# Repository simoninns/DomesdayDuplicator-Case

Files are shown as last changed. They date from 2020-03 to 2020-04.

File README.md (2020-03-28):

# Introduction
This repository contains a 3D printable case design for the Domesday Duplicator.

The case is designed using OpenSCAD and full source code is included.  There are also ready-made STL files for the various parts and materials if you don't want to build them yourself in OpenSCAD.

The case design contains multiple materials however you can easily remix the design using OpenSCAD customization GUI if you wish to print in a single material only (simply deselect the 'fill out text' and 'add logo' options and re-render).  Ready-made single material STL files are also included.

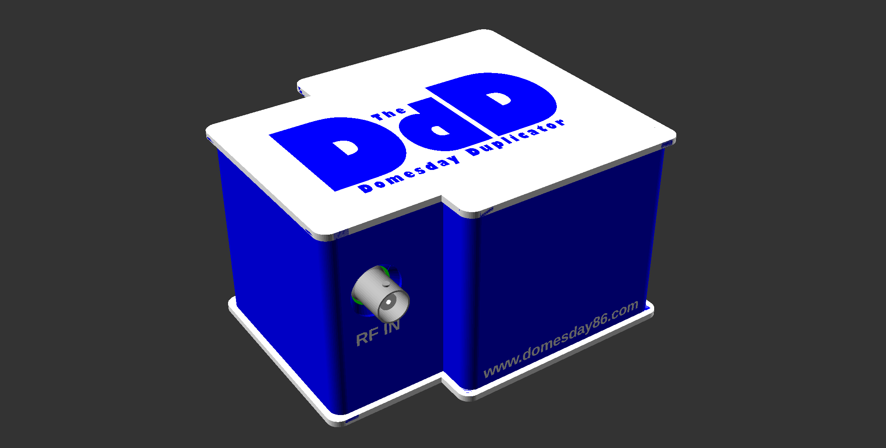
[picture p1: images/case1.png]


# Printing instructions

## Overview

The model has been printed and tested on the Prusa MK3S/MMU2S printer. All parts fit on a 20x20 printing bed.

The OpenSCAD source files provide a parameter interface that allows you to render either the whole model or the individual parts (ready for STL (or other 3D format) export).  This requires OpenSCAD 2019.05 or later.

## Recommended print settings
* Material: PLA Blue and PLA White
* Layer: 0.20mm (Quality)
* Infill: 15%
* Supports: None
* Notes: The upper and lower case parts simply snap together.  4x M3 6mm screws are required to hold the electronics in place.

## Print time
Clearly this depends on your printer and it's settings.  For the 2 colour multi-material print the time was 11h 15m for both the upper and lower case.  For single-material printing to time was 8h 30m.

## Notes
The design also includes approximate renderings of the FPGA board, the DdD board and the USB3 board.  These are to assist with the design process and are not intended for printing.

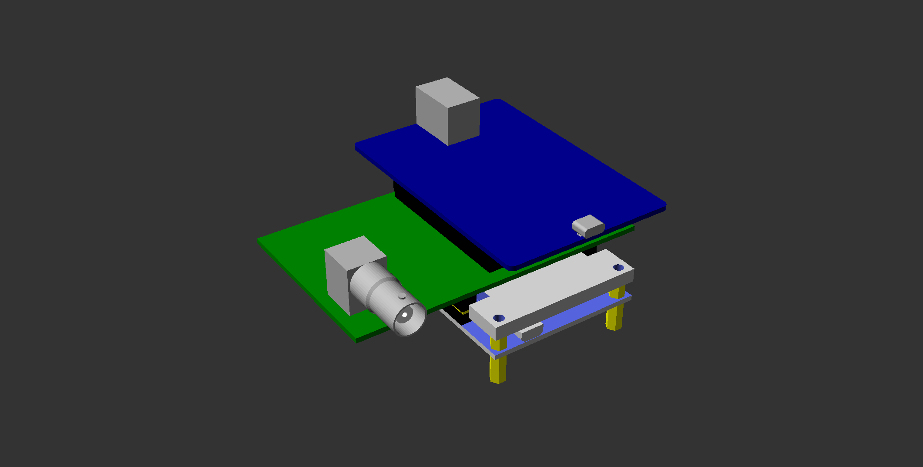
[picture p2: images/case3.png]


# Author

The DomesdayDuplicator case is designed and maintained by Simon Inns.

# Licensing

## OpenSCAD source files - software license (GPLv3)

    This is free software: you can redistribute it and/or modify
    it under the terms of the GNU General Public License as published by
    the Free Software Foundation, either version 3 of the License, or
    (at your option) any later version.
    
    This program is distributed in the hope that it will be useful,
    but WITHOUT ANY WARRANTY; without even the implied warranty of
    MERCHANTABILITY or FITNESS FOR A PARTICULAR PURPOSE.  See the
    GNU General Public License for more details.
    
    You should have received a copy of the GNU General Public License
    along with this program.  If not, see <http://www.gnu.org/licenses/>.

## 3D model file - Creative Commons license (Creative Commons BY-SA 4.0)

Please see the following link for details: https://creativecommons.org/licenses/by-sa/4.0/

You are free to:

Share - copy and redistribute the material in any medium or format
Adapt - remix, transform, and build upon the material
for any purpose, even commercially.

This license is acceptable for Free Cultural Works.

The licensor cannot revoke these freedoms as long as you follow the license terms.

Under the following terms:

Attribution - You must give appropriate credit, provide a link to the license, and indicate if changes were made. You may do so in any reasonable manner, but not in any way that suggests the licensor endorses you or your use.

ShareAlike - If you remix, transform, or build upon the material, you must distribute your contributions under the same license as the original.

No additional restrictions - You may not apply legal terms or technological measures that legally restrict others from doing anything the license permits.

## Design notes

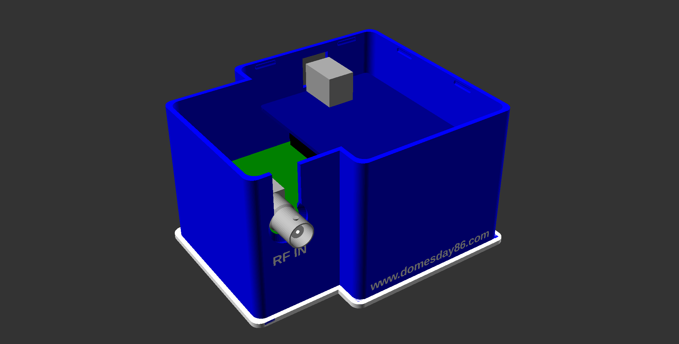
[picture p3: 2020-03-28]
images/case2.png

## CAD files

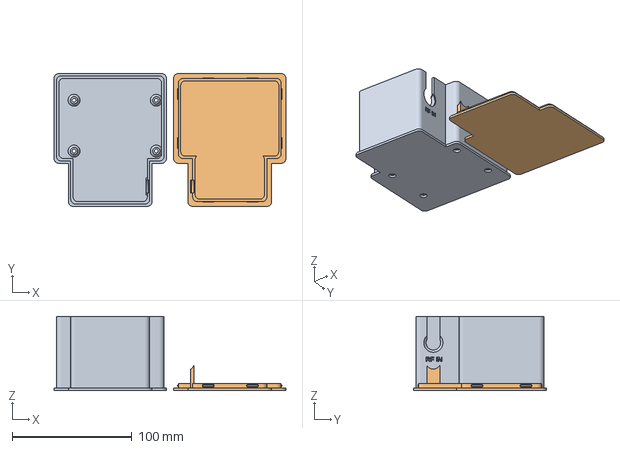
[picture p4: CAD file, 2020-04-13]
3mf/multi_material.3mf
193.9 x 111.0 x 62.0 mm
base_material1.stl
top_material1.stl

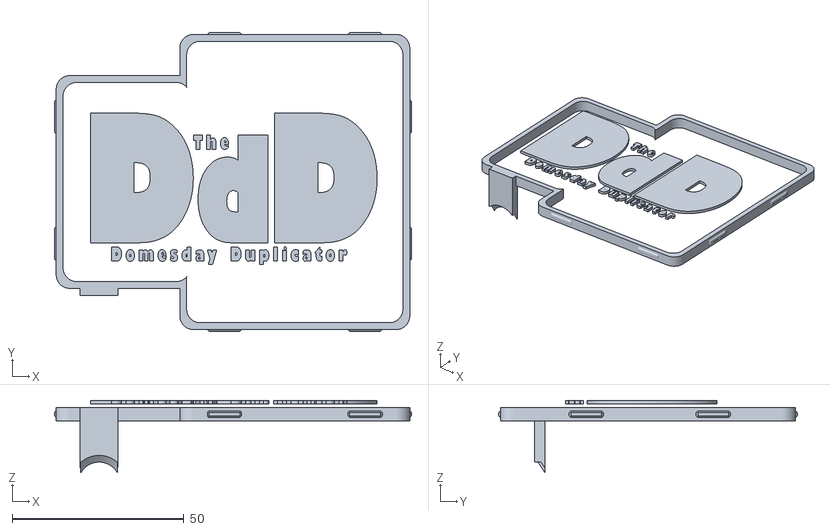
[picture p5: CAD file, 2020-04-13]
stl/top_material2.stl
104.0 x 87.0 x 21.0

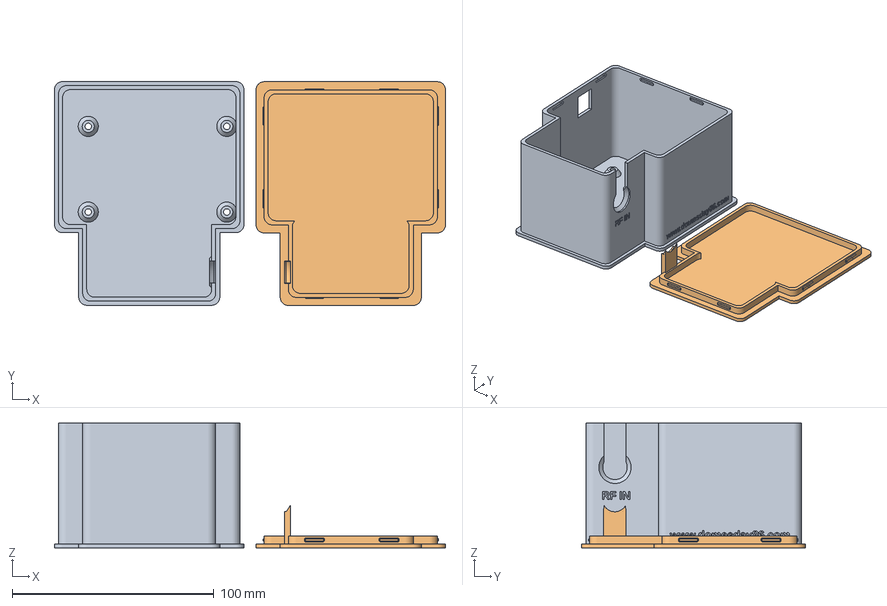
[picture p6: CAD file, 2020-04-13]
3mf/single_material.3mf
194.0 x 111.1 x 62.0 mm
single_material_base.stl
single_material_top.stl

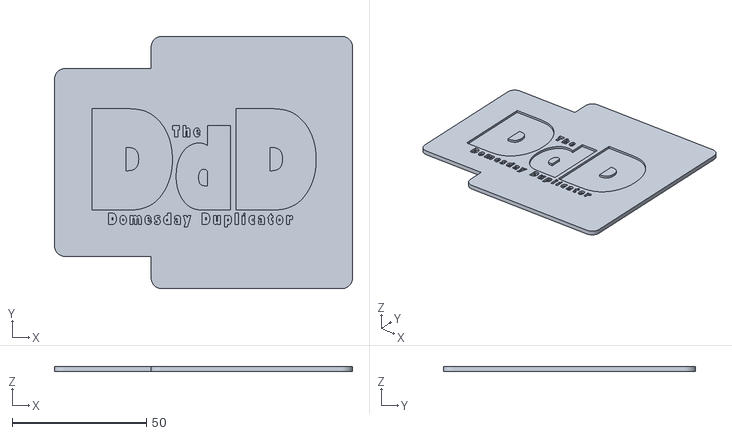
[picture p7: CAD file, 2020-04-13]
stl/top_material1.stl
111.0 x 94.0 x 2.00

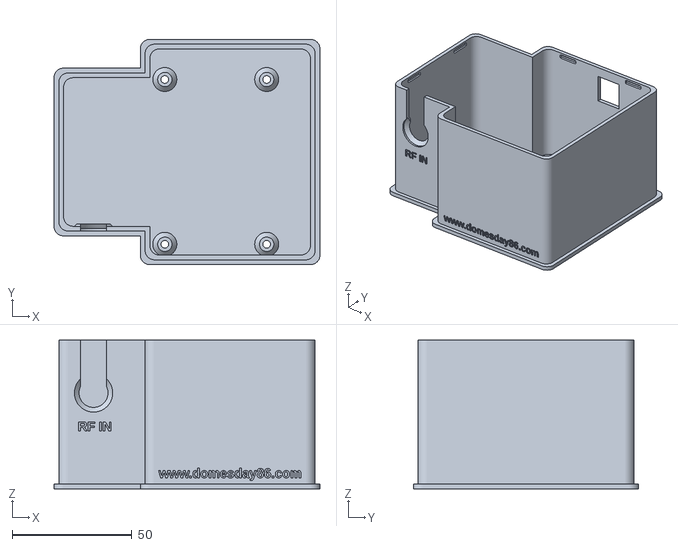
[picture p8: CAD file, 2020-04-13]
stl/single_material_base.stl
111.0 x 94.0 x 62.0

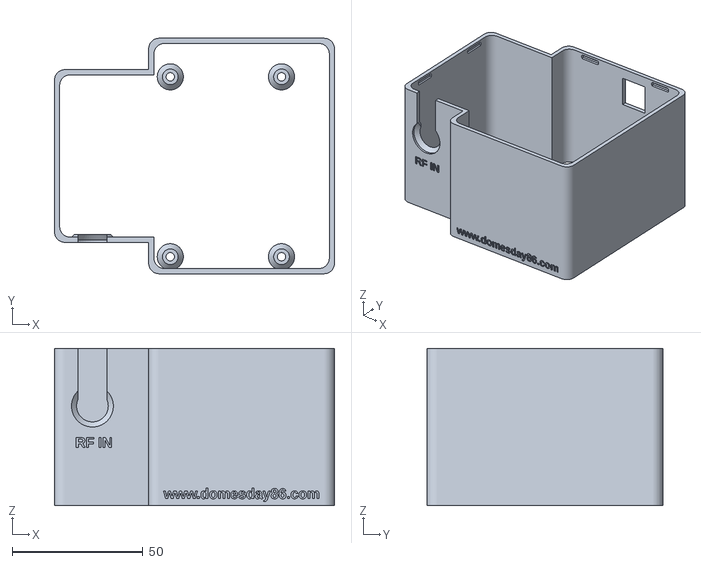
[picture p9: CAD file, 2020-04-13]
stl/base_material2.stl
107.0 x 90.0 x 60.0

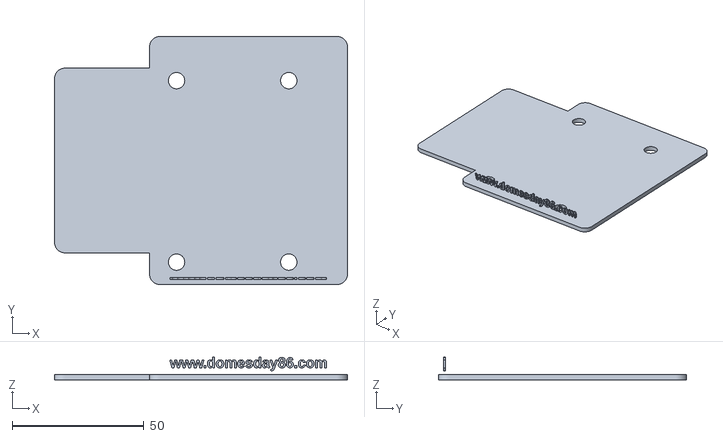
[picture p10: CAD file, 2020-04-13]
stl/base_material1.stl
111.0 x 94.0 x 8.63

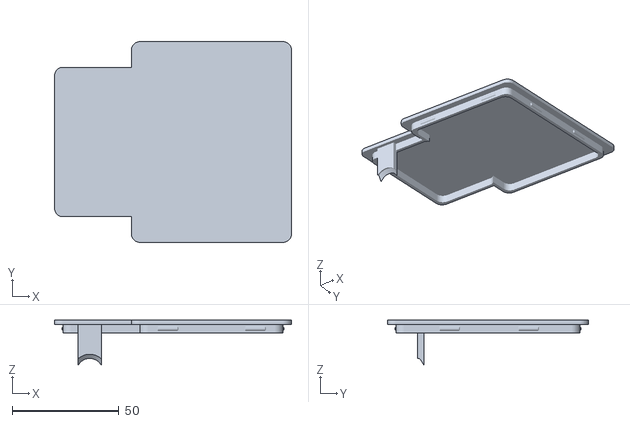
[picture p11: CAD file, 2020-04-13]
stl/single_material_top.stl
111.0 x 94.0 x 21.0

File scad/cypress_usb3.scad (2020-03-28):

/************************************************************************

	cypress_usb3.scad
    
	Domesday Duplicator - 3D Printed Case
    Copyright (C) 2020 Simon Inns
	
    This file is part of Domesday Duplicator.
    
    This is free software: you can redistribute it and/or modify
	it under the terms of the GNU General Public License as published by
	the Free Software Foundation, either version 3 of the License, or
	(at your option) any later version.
    
    This program is distributed in the hope that it will be useful,
    but WITHOUT ANY WARRANTY; without even the implied warranty of
    MERCHANTABILITY or FITNESS FOR A PARTICULAR PURPOSE.  See the
    GNU General Public License for more details.
    
    You should have received a copy of the GNU General Public License
    along with this program.  If not, see <http://www.gnu.org/licenses/>.
	
    Email: simon.inns@gmail.com
    
************************************************************************/

include <BOSL/constants.scad>
use <BOSL/shapes.scad>
use <BOSL/transforms.scad>

// Draw the female header (7mm pins)
module usb3_female_header()
{
    color("black") cuboid([5,51,8], center = false);
}

// Draw the PCB
module usb3_pcb()
{
    color("darkblue") cuboid([56, 82.3, 1.6], center = false, fillet = 2, edges = EDGE_BK_RT+EDGE_BK_LF+EDGE_FR_RT+EDGE_FR_LF);
}

// Draw the USB3 connector
module usb3_usbheader()
{
    color("darkgrey") {
        move([(56 / 2) - 3.5,82.3 - 18,1.6]) cuboid([12,18,13], center = false);
    }

    color("blue") {
        move([(56 / 2) - 2,82.3 - 18 + 1,2.6]) cuboid([9,17.01,7], center = false);
        move([(56 / 2) - 0,82.3 - 18 + 1,2.6 + 7]) cuboid([5,17.01,4], center = false);
    }
}

// Draw the debug USB connector
module usb3_microheaader()
{
    color("darkgrey") {
        move([(56 / 2) - 3.5,-0.5,1.6]) cuboid([7,5.5,3], center = false, fillet = 1, edges = EDGE_TOP_LF+EDGE_TOP_RT+EDGE_BOT_LF+EDGE_BOT_RT);
    }
}

// Render the Cypress USB3 board
module render_usb3()
{
    move([0,0,0]) usb3_pcb();
    move([4.5,15,-8]) usb3_female_header();
    move([51 - 4.5,15,-8]) usb3_female_header();

    move([0,0,0]) usb3_usbheader();
    move([0,0,0]) usb3_microheaader();
}

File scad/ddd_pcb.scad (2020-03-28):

/************************************************************************

	ddd_pcb.scad
    
	Domesday Duplicator - 3D Printed Case
    Copyright (C) 2020 Simon Inns
	
    This file is part of Domesday Duplicator.
    
    This is free software: you can redistribute it and/or modify
	it under the terms of the GNU General Public License as published by
	the Free Software Foundation, either version 3 of the License, or
	(at your option) any later version.
    
    This program is distributed in the hope that it will be useful,
    but WITHOUT ANY WARRANTY; without even the implied warranty of
    MERCHANTABILITY or FITNESS FOR A PARTICULAR PURPOSE.  See the
    GNU General Public License for more details.
    
    You should have received a copy of the GNU General Public License
    along with this program.  If not, see <http://www.gnu.org/licenses/>.
	
    Email: simon.inns@gmail.com
    
************************************************************************/

include <BOSL/constants.scad>
use <BOSL/shapes.scad>
use <BOSL/transforms.scad>

// Draw the BNC connector
module bnc_connector()
{
    // Rosenberger 51K204-400A5
    color("darkgrey") {
        difference() {
            union() {
                move([-6,0,0]) cuboid([12,12, 18.5 - 4], center = false);
                move([0,0,9]) rotate([90,0,0]) cyl(h=8.1, r=5.5, center = false);
                move([0,-8.1,9]) rotate([90,0,0]) cyl(h=1, r1=5.5, r2=5, center = false);
                move([0,-8.1,9]) rotate([90,0,0]) cyl(h=12.5, r=5, center = false);

                // Bayonet pins
                move([0,-17.1,3.5]) rotate([0,0,0]) cyl(h=11, r=1, center = false);
            }

            move([0,-8.2,9]) rotate([90,0,0]) cyl(h=12.5, r=4.5, center = false);
        }

        // Connection pins
        move([6 - 1,1,-4]) cyl(h=4, r=0.6, center = false);
        move([-6 + 1,1,-4]) cyl(h=4, r=0.6, center = false);

        move([6 - 1,10 + 1,-4]) cyl(h=4, r=0.6, center = false);
        move([-6 + 1,10 + 1,-4]) cyl(h=4, r=0.6, center = false);

        move([0,6,-4]) cyl(h=4, r=0.45, center = false);
    }

    color("white") {
        // Center part of BNC plug (for decoration)
        move([0,-8,9]) rotate([90,0,0]) tube(h=10, ir = 0.75, or=2.5, center = false);
    }
}

// Draw the PCB
module pcb()
{
    color("green") {
        move([0,-27,-1.6 / 2]) cuboid([95,57,1.6], center = false);
    }
}

// Draw a male pin header (7mm pins)
module male_header()
{
    color("black") cuboid([5,50,3], center = false);
    color("yellow") move([1,0.5,3]) cuboid([3,49,7], center = false);
}

// Draw a female pin header (7 mm pins)
module female_header()
{
    color("black") cuboid([5,51,8], center = false);
}

// Draw the headers
module headers()
{
    // Top headers
    move([45.5,-22.5,1.6 / 2]) male_header();
    move([87.5,-22.5,1.6 / 2]) male_header();

    // Bottom headers
    move([36,-22.75,-8.7]) female_header();
    move([79.5,-22.75,-8.7]) female_header();
}

// Render the DdD PCB and components
module render_ddd_pcb()
{
    move([9.6,-17.8,1.6 / 2]) bnc_connector();
    pcb();
    headers();
}

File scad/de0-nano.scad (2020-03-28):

/************************************************************************

	de0-nano.scad
    
	Domesday Duplicator - 3D Printed Case
    Copyright (C) 2020 Simon Inns
	
    This file is part of Domesday Duplicator.
    
    This is free software: you can redistribute it and/or modify
	it under the terms of the GNU General Public License as published by
	the Free Software Foundation, either version 3 of the License, or
	(at your option) any later version.
    
    This program is distributed in the hope that it will be useful,
    but WITHOUT ANY WARRANTY; without even the implied warranty of
    MERCHANTABILITY or FITNESS FOR A PARTICULAR PURPOSE.  See the
    GNU General Public License for more details.
    
    You should have received a copy of the GNU General Public License
    along with this program.  If not, see <http://www.gnu.org/licenses/>.
	
    Email: simon.inns@gmail.com
    
************************************************************************/

include <BOSL/constants.scad>
use <BOSL/shapes.scad>
use <BOSL/transforms.scad>

// Draw a male pin header (7mm pins)
module male_nano_header()
{
    color("black") cuboid([5,50,3], center = false);
    color("yellow") move([1,0.5,3]) cuboid([3,49,7], center = false);
}

// Draw the DE0-Nano FPG board
module render_de0_nano()
{
    move([0,-75.18,0]) {
        difference() {
            cuboid([49.02, 75.18, 11], center = false);

            // Seperate PCB and case
            move([-0.5,-0.5,1.6]) cuboid([50, 76, 5], center = false);

            // Screw holes
            move([3.3, 3.05, 5.5]) cyl(h=13, r = 1.6);
            move([45.72, 3.05, 5.5]) cyl(h=13, r = 1.6);

            move([3.3, 71.88, 5.5]) cyl(h=13, r = 1.6);
            move([45.72, 71.88, 5.5]) cyl(h=13, r = 1.6);

            // Cutouts for header pins
            move ([-0.01,12.5,1.6]) cuboid([7, 57, 11], center = false);
            move ([45.72 - 3.7 + 0.01,12.5,1.6]) cuboid([7, 57, 11], center = false);

            // Cutout for mini USB connector
        }
    }

    // Header pin rows
    move([0,-75.18 + 16.26,1.6]) male_nano_header();
    move([49.02 - 5,-75.18 + 16.26,1.6]) male_nano_header();

    color("yellow") move([0,-75.18,0]) {
        // Standoffs
        $fn = 6;
        move([3.3, 3.05, -5]) cyl(h=10, r = 2.5);
        move([45.72, 3.05, -5]) cyl(h=10, r = 2.5);

        move([3.3, 71.88, -5]) cyl(h=10, r = 2.5);
        move([45.72, 71.88, -5]) cyl(h=10, r = 2.5);
    }

    color("yellow") move([0,-75.18,9]) {
        // Standoffs
        $fn = 6;
        move([3.3, 3.05, -5]) cyl(h=5.4, r = 2.5);
        move([45.72, 3.05, -5]) cyl(h=5.4, r = 2.5);

        move([3.3, 71.88, -5]) cyl(h=5.4, r = 2.5);
        move([45.72, 71.88, -5]) cyl(h=5.4, r = 2.5);
    }

    // USB mini connector
    move([9,-75,1.6]) cuboid([7.5,9,3.5], center = false, chamfer = 1.2, edges = EDGE_BOT_LF+EDGE_BOT_RT);
}

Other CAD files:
scad/lower_case.scad
scad/main.scad
scad/material.scad
scad/upper_case.scad

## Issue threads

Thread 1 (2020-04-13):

Multi-material lid optimisation

simoninns, 2020-04-13:
It would be better if the tab for the BNC connector used the same material as the lid up to the top of the lip.  This would reduce tool changes and speed up multi-material printing

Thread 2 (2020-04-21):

Incorrect origins

toynbeeidea, 2020-04-21:
Tried ordering a set off of Treatstock, got the following message:

"The vendor says that the files have incorrect origins so MMU parts are misaligned. Do you have an ability to fix the models?"

simoninns, 2020-04-21:
I'm not really sure what they mean... PrusaSlicer has no issues with it (and I've printed 4 mutli-material cases on my MMU2S based Prusa i3).  Of course, the full OpenSCAD source is available (so you can produce any STL files you like) - but, if I understood the issue clearly, I'd probably be able to fix it; so, if possible, ask them for more details please.

Here are the STLs from the repo loaded into the slicer (I just did this to check) - no reported errors:

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

gmccauley, 2020-04-21:
It looks like Treatstock must manipulate the files somehow when uploading them (resetting the origins to the absolute middle of the object, thus the mis-alignment).  See screenshot below of what it looks like when loading the files provided via Treatstock into PrusaSlicer.  I have confirmed that loading the files located in the repo are aligned correctly.

@toynbeeidea - If you contact me directly (george at grm-3d.com) I can give you a little better price than through Treatstock.

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

simoninns, 2020-04-21:
I'm not really sure how to 'correct' it so that doesn't happen.  In OpenSCAD the materials are simply 'excluded' to make the various STL files, so their location in 3D space should be correct (the lid should be flipped 180 degrees in the slicer to lay flat though - which is shown in the included .3mf files).

toynbeeidea, 2020-04-25:
I guess really its Treatstock's error, not really anything to do with the files themselves. Maybe worth a note of warning on the front page though?

Closed 2020-04-25.

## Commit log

2020-03-28 Added project files
    [base_material1.stl, base_material2.stl, case_multimaterial.3mf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]
2020-04-13 Modifications for easier multi-material print and fix for issue #1
    [base_material1.stl, base_material2.stl, case_multimaterial.3mf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]
